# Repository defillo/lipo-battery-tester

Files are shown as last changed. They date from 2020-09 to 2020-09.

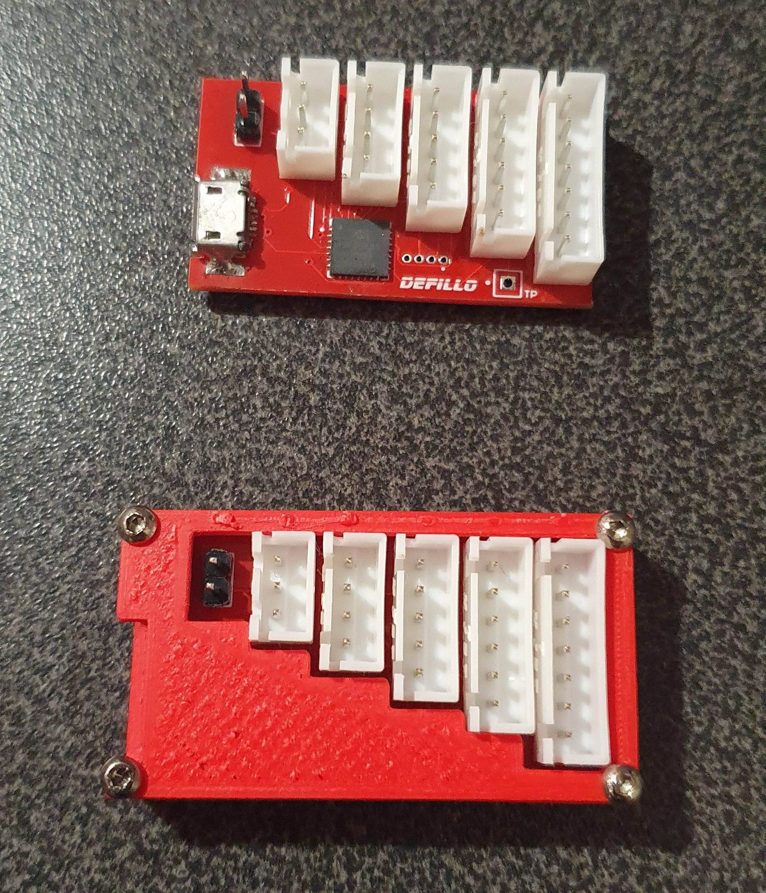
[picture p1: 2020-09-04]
20200904_072448.jpg

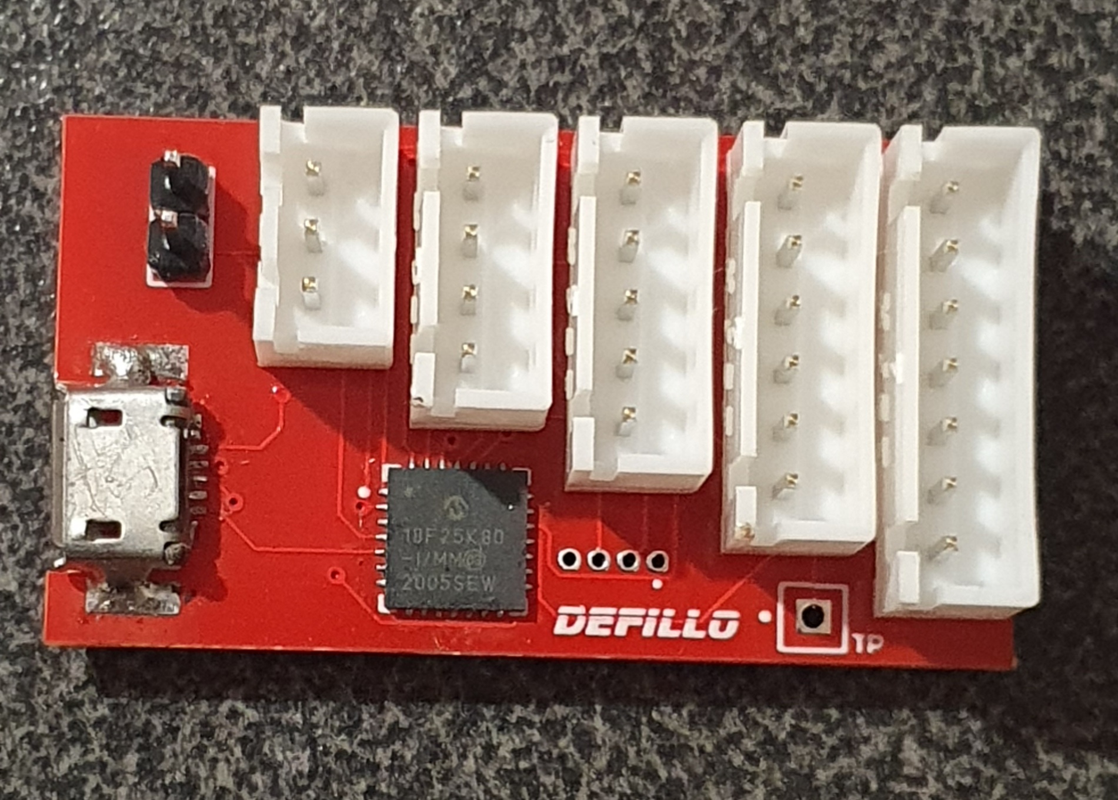
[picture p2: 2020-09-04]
20200904_072419.jpg

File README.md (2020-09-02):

# lipo-battery-tester
Lipo battery tester 1S..6S  with instant reading and validation of cells, outputs on Android app via OTG Usb cable

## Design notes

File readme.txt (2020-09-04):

License. this project is distributed free for personal use. Yhis means that you can produce your own unit(s) but you are not allowed to make a commercial use of this item
If you want to produce and sell the units, please contact the developer at  defilippi1962@gmail.com

Assemly is not difficult. care must be taken in welding MCU and FTDI chip
For MCU, use hotair if available

Programming:

Use devicessuch as PICKIT4 or PICKIT3
Use MPLABX IPE v.5.40 or newer

Need 4 pins for programming Vpp,GND,PGD,PGDC, board as a small 4way, 1 mm pitch connector. dot is Vpp
Please take care that the 1S connector has no key. inserting battery probe reversed causes permanent damage at leat to the MCU so be careful

FTProg is used to program the FTDI chip with the String descriptor you like.
device vendor and ID are the standard ones, do not change them otherwise the Android app will not open automatically 

Calibration:
Connect to the board with a PC or android device with a serial emulator (for pc, you might need to install ftdi drivers), set baudrate to 57600

Usually the reference voltage value will be 4.500 volt as stated by the Analog Devices datasheet, for what concerns REF194
If you have a very good instrument and you want to deep calibrate the system, check the voltage at pin TP and take note of the value
now multiply by 100 and set as an INT (example: reading is 4.5231, * 100 = 452.31 , set to INT and you get 452)
then send the command V:452 check for the confirm and that's all. 
Firmware defaults to 4.50 if no voltage calibration is issued

using the   TP point with 4.500 V output

Use a short wire and start connecting the 6S pole to this TP
Connect to the board with a PC or android device, set baudrate to 57600

After connecting the 1S wire to the TP, send C:1 <enter> to the board. Calibration of 1S resistor ladder will be stored in flash
proceed with 2S sending C:2, then 3S with C:3 always connecting the relevant pin to TP and so on up to C:6

You will read a reply with the relevant ratio factor in the end. value must be closer to the number of cells
Example. calibrating 4S  will report a factor around 4 and so on

Calibration is stored in the MCU flash so no need to do it again unless you flash the board again
That case is better to preserve EEPROM area in MPLABX IPE

APP

The app will immediately show the 
1)total Voltage
2 the charge percentage (based on 4.20 = 100% , 3.3V = 0%)
3)the different cells voltages
4) The mean value of the cells
5) The percentage of charge of each cells
6) The deviation of the voltage of the cell on respect of the mean value. shown in millivolts

If you prefere to have the board already mounted and running, please ask by mail to
defilippis1962@gmail.com

In any case, there will be NO responsability of the author for any damage that may occur under any circumstances to any object that can be related to this project

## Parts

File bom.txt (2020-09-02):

Comment	Description	Designator	Footprint

10K		R2, R4, R6, R8, R9, R10	0805	
20K		R7	0805
30K		R5	0805
40K2	R3	0805
4K7		R0	0805
51K		R1	0805
REF194	UREF	REF194
PIC18F25K80		MCU	QFN-ML28_N
Header 7	Header, 7-Pin	JST B7B-XH-A(LF)(SN)	
Header 6	Header, 6-Pin	JST B6B-XH-A(LF)(SN)
Header 5	Header, 5-Pin	JST B5B-XH-A(LF)(SN)
Header 4	Header, 4-Pin	JST B4B-XH-A(LF)(SN)
Header 3	Header, 3-Pin	JST B3B-XH-A(LF)(SN)
Header 2	Header, 2-Pin	STRIP 2.54	
FT230X		U2	FTDI FT230X	
CON5	USB	microusb	AMPHENOL FCI 10104111-0001LF
100nF	C1, C2	0805
1uF		C3	0805

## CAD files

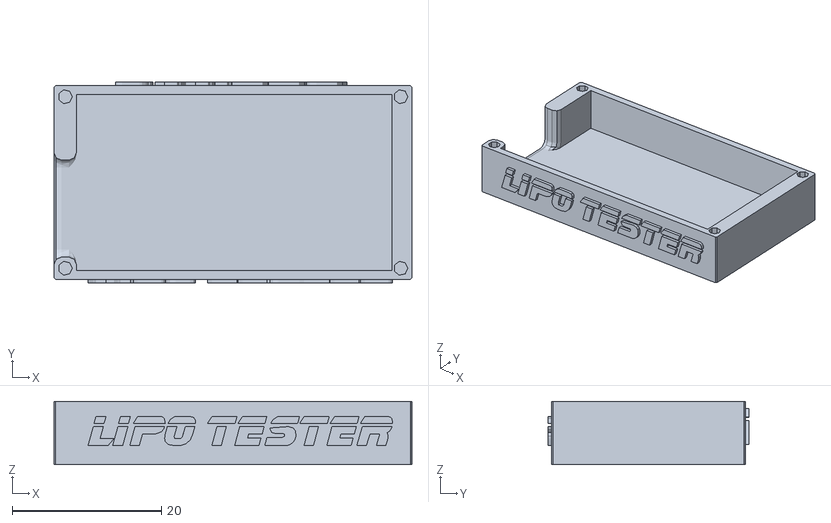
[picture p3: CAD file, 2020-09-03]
battery tester case.stl
48.0 x 27.0 x 8.50

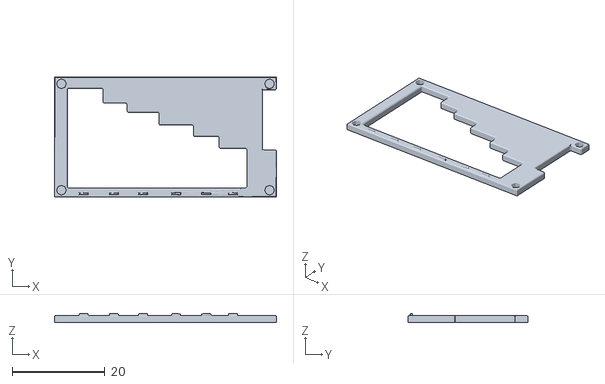
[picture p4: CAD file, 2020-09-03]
battery tester coperchio.stl
48.0 x 26.0 x 2.00

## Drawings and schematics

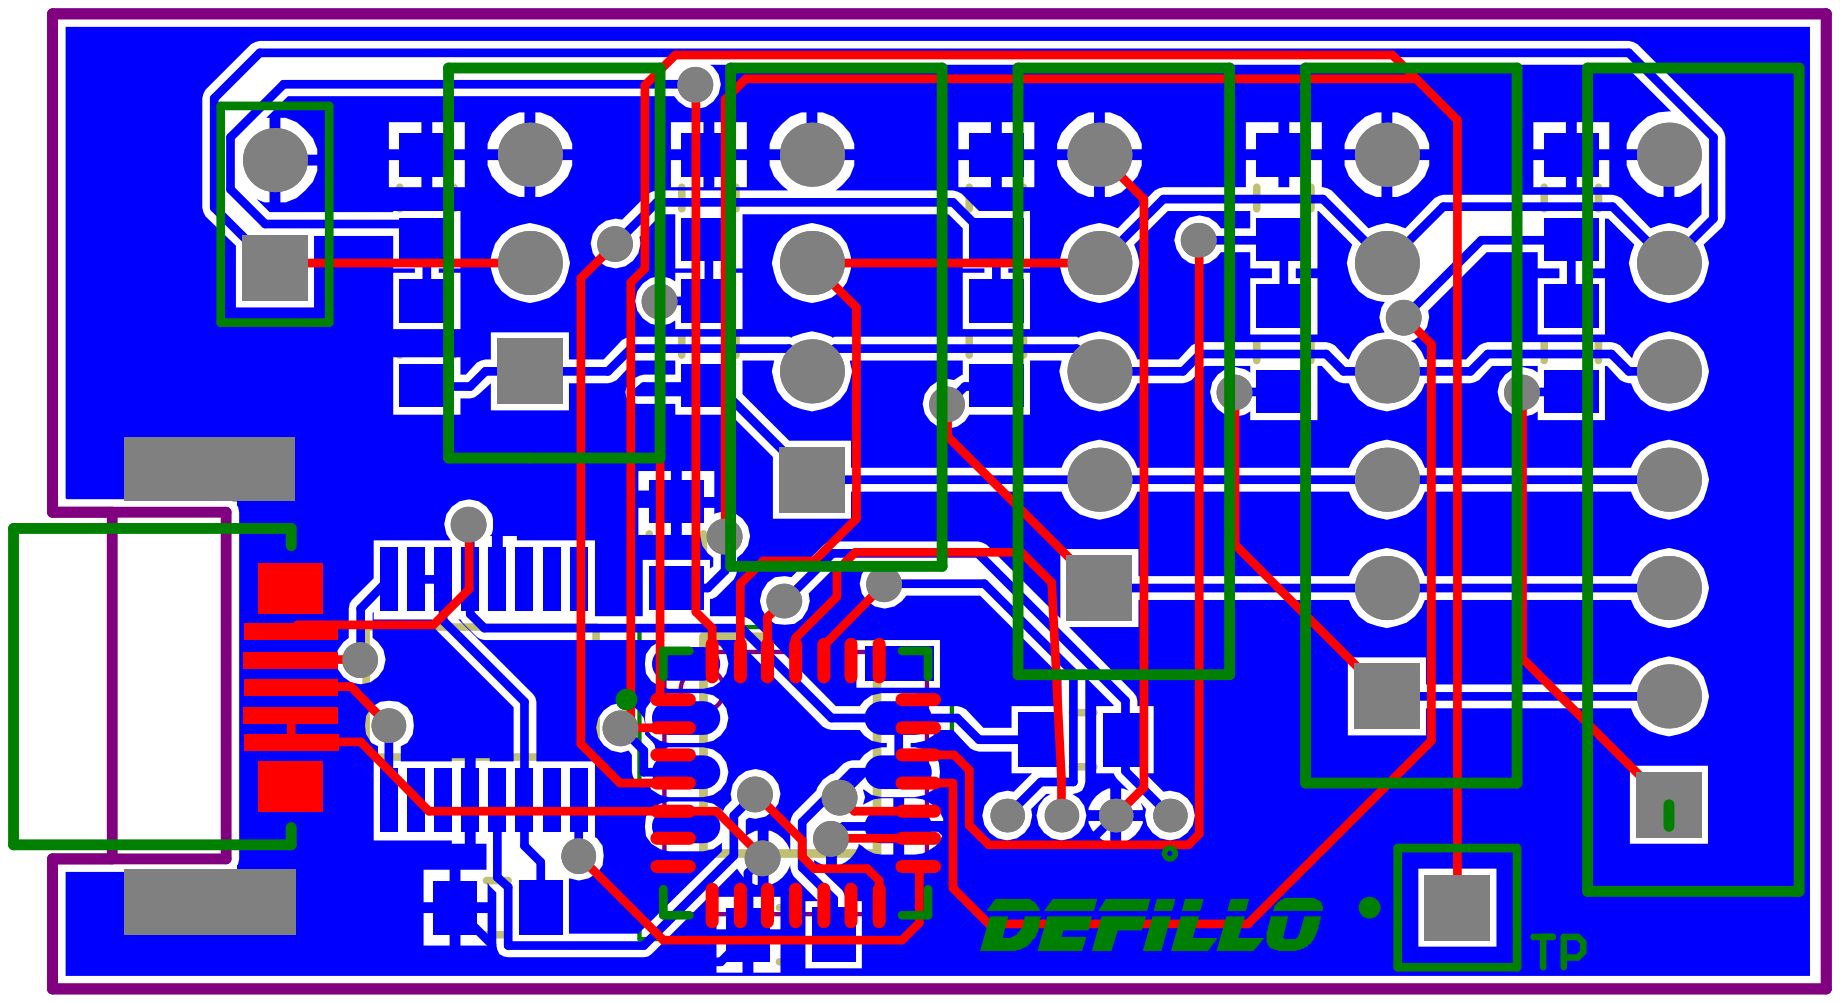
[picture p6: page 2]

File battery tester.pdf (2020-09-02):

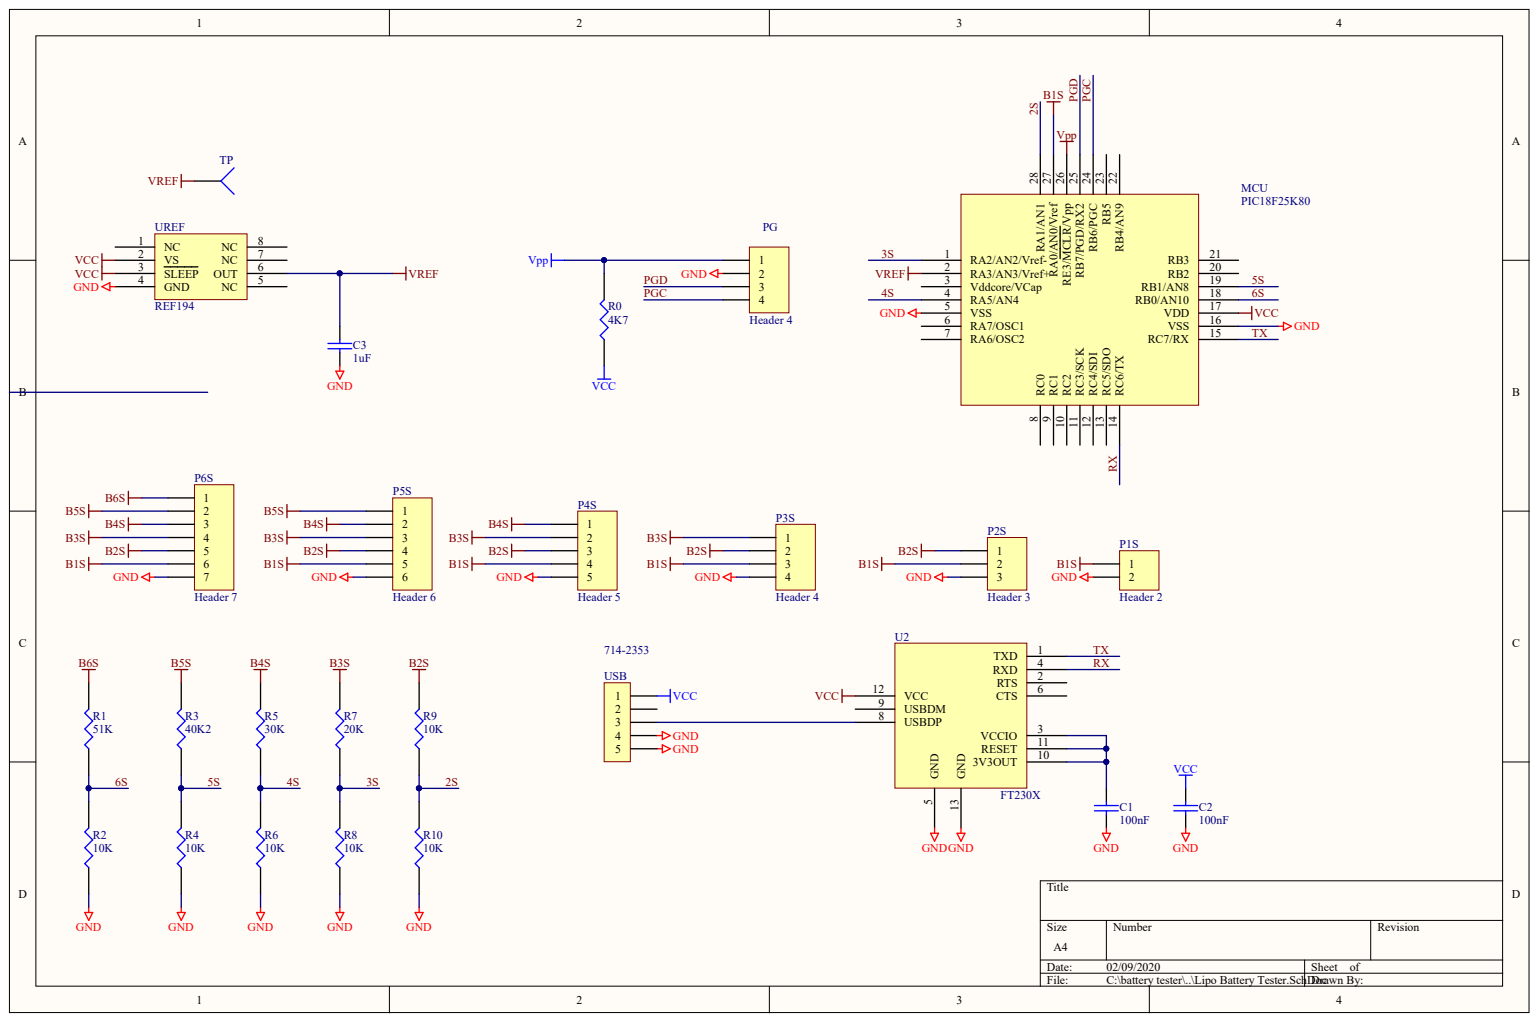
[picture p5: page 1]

N9 22 RB5 23 RB6/PGC 24 RB7/PGD/RX2 25 RE3/MCLR/Vpp 26 RA0/AN0/Vref 27 RA1/A
